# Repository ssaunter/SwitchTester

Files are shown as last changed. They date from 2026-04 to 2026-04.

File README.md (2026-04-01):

# SwitchTester
 
 SwitchTester is a 5-key switch PCB and housing to test the feel of different Cherry MX switches. Addressable LEDs have two modes: always on (colored), and fade when pressed.

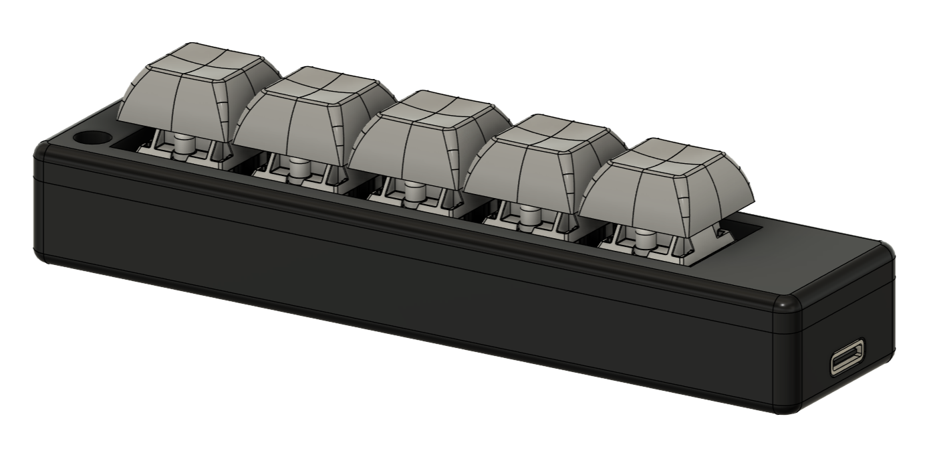
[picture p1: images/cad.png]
Full Cad


# The PCB

The PCB follows a similar architecture to the Hackpad, and upgrades with decoupling capacitors and a switch to control LED modes. The code is set up to adjust the LED modes depending on the slide switch mode.

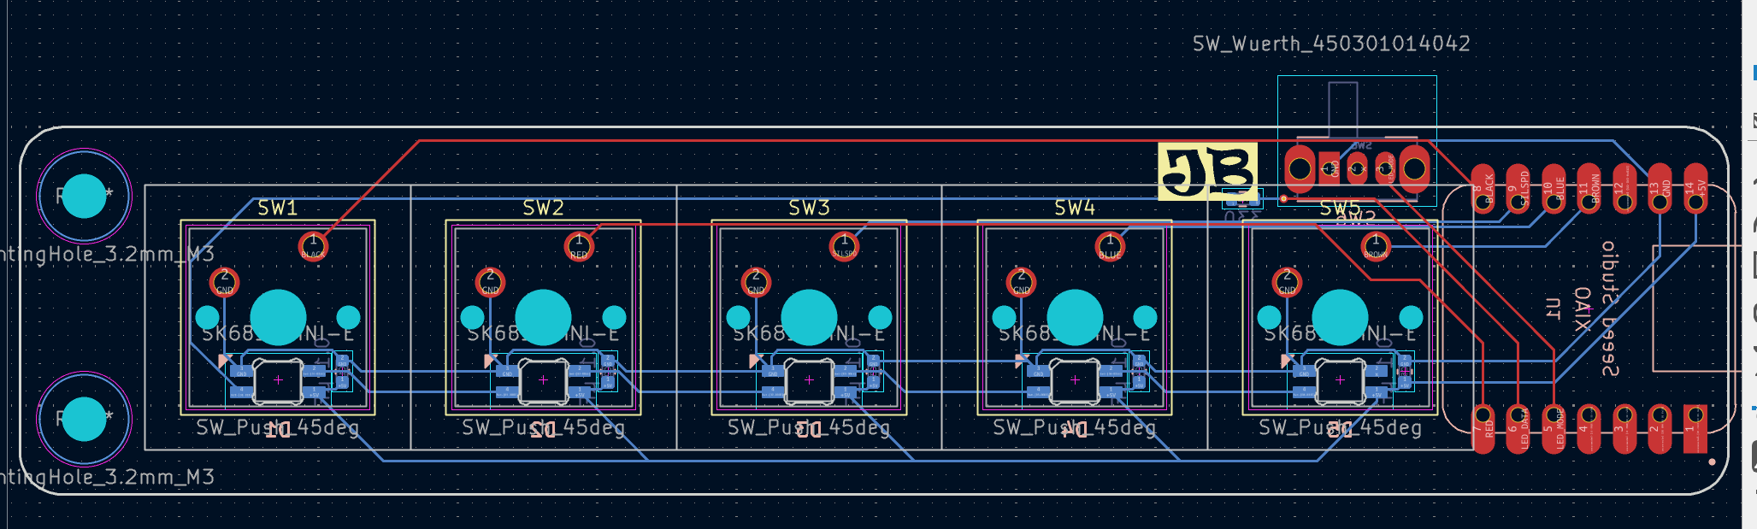
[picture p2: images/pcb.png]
PCB


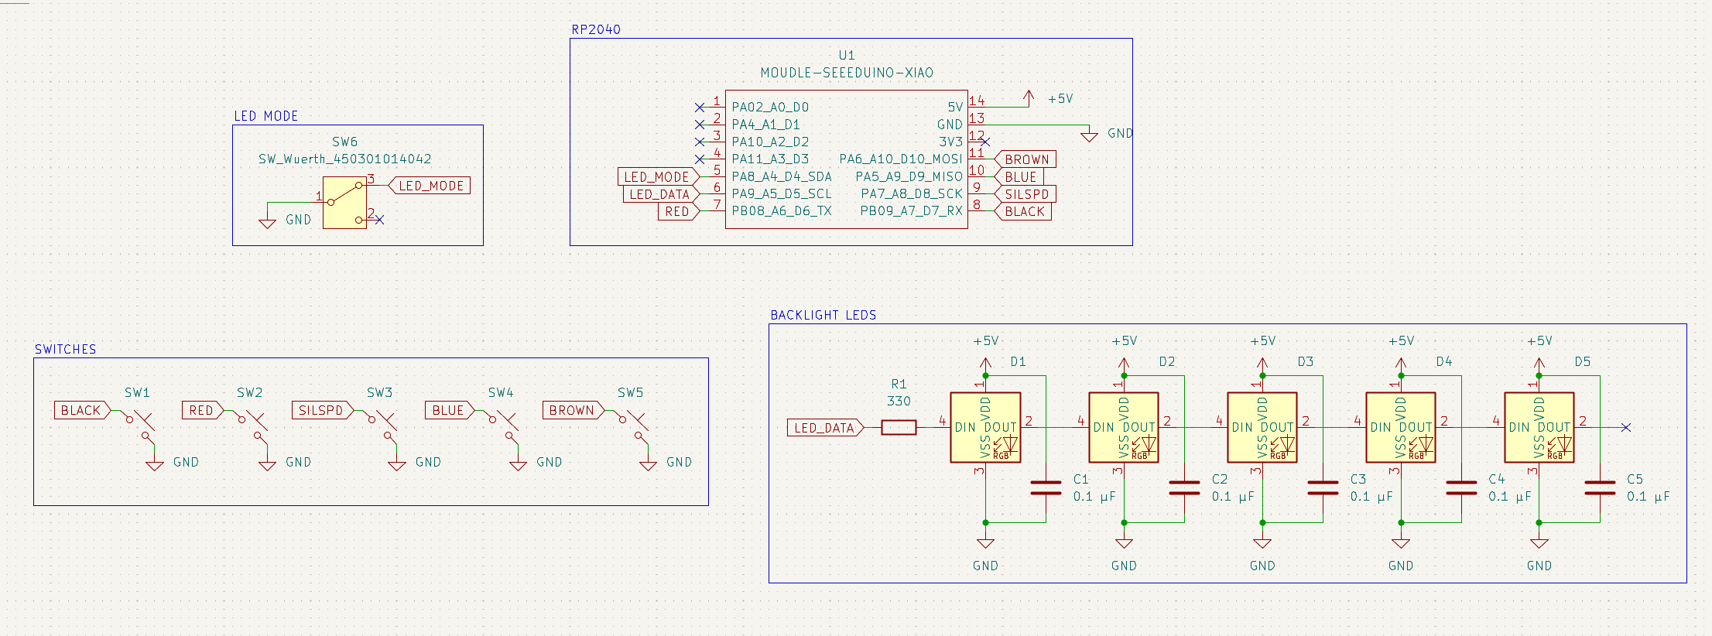
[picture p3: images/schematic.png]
Schematic


# Assembly

The lower and upper case sections are to be 3D printed. The device is assembled using 2x M3x5x5 heatset inserts and 2x M3x10 bolts. The PCB is aligned in the lower case, and the top case encloses it before being bolted down through the standoffs. It should be stable enough, but the USB-C recepticle also nicely rests into the opposite side for added stability. If I find that it is unstable even then, I can add standoffs without holes thoughout the lower case.

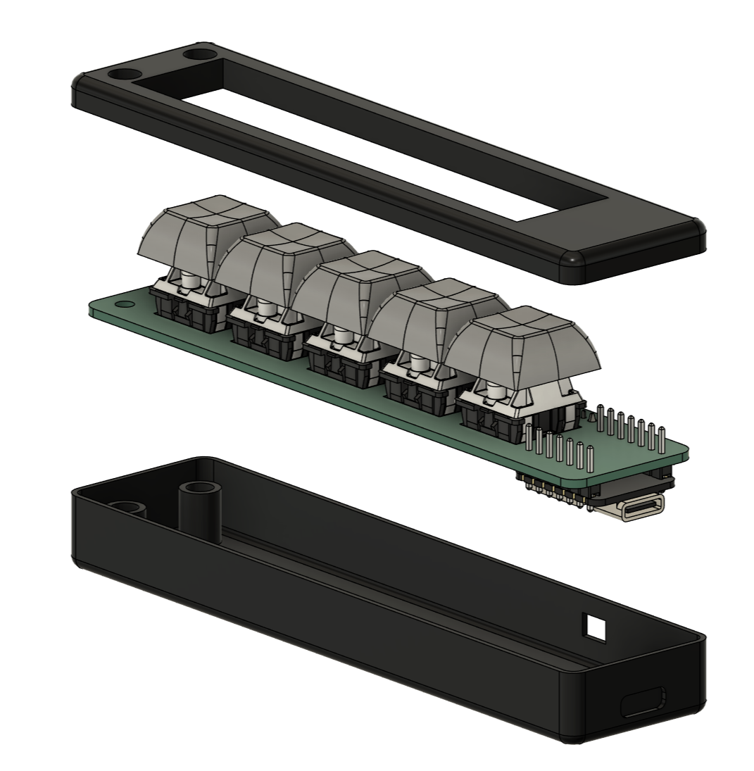
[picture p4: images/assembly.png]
Assembly


# Firmware

The code was created in the Arduino IDE, and uses the FastLED library for the SMD LEDs. The colors are based on guesses, and I will change the code after testing the values.

The first section of the code is simply setup and definitions. It sets the switches as inputs and assigns the pullup resistors, and also initializes the LED index.

The main loop determines the current LED_MODE, checks for keyswitch presses, and outputs to the LED based on the mode and user interaction. FastLED.show() is used to queue the LED instructions and send data through the LED_DATA line.

# BOM

| Part | Quantity | Price Per | Link | 
| :--- | :---: | :---: | :--- |
| **Seeduino Xiao** | 1 | $4.68 | [DigiKey](https://www.digikey.com/short/d3zzwm59) |
| **Slide Switch** | 1 | $0.65 | [DigiKey](https://www.digikey.com/short/p00mmw27) |  
| **0.1uF C 0603** | 5 | $0.08 | [DigiKey](https://www.digikey.com/short/3rn2v9pz) |
| **330ohm R 0603** | 1 | $0.10 | [DigiKey](https://www.digikey.com/short/2qztp77r) |
| **Neopixel LED 10pcs** | 1 | $2.95 | [DigiKey](https://www.digikey.com/short/n79w9mvw) |
| **Cherry MX Blue 60g** | 1 | $0.38 | [MechanicalKeyboards](https://mechanicalkeyboards.com/products/cherry-mx-blue-60g-clicky?variant=48007305003308) |
| **Cherry MX2A Red** | 1 | $0.38 | [MechanicalKeyboards](https://mechanicalkeyboards.com/products/cherry-mx2a-red-45g-linear?variant=48020634239276) |
| **Cherry MX2A Black** | 1 | $0.38 | [MechanicalKeyboards](https://mechanicalkeyboards.com/products/cherry-mx2a-black-60g-linear?variant=48014721253676) |
| **Cherry MX2A Brown** | 1 | $0.38 | [MechanicalKeyboards](https://mechanicalkeyboards.com/products/cherry-mx2a-brown-55g-tactile?variant=48020838383916) |
| **Cherry MX Blue 60g** | 1 | $0.38 | [MechanicalKeyboards](https://mechanicalkeyboards.com/products/cherry-mx-blue-60g-clicky?variant=48007305003308) |
| **DSA Keycaps** | 5 | (have) |  |
| **1x7 Male Headers** | 2 | (have) |  |
| **M3x5x5 Heatset Inserts** | 2 | (have) |  |
| **M3x10 Bolt** | 2 | (have) |  |

Totals
---
| Service  | Price | 
| :--- | :--- |
| **JLCPCB Order** |  $8.52 | 
| **DigiKey Order** |  $16.92 | 
| **MechanicalKeyboards Order** |  $12.54 | 
| **GRAND TOTAL:** |  $37.98 | 

Orders: 
---

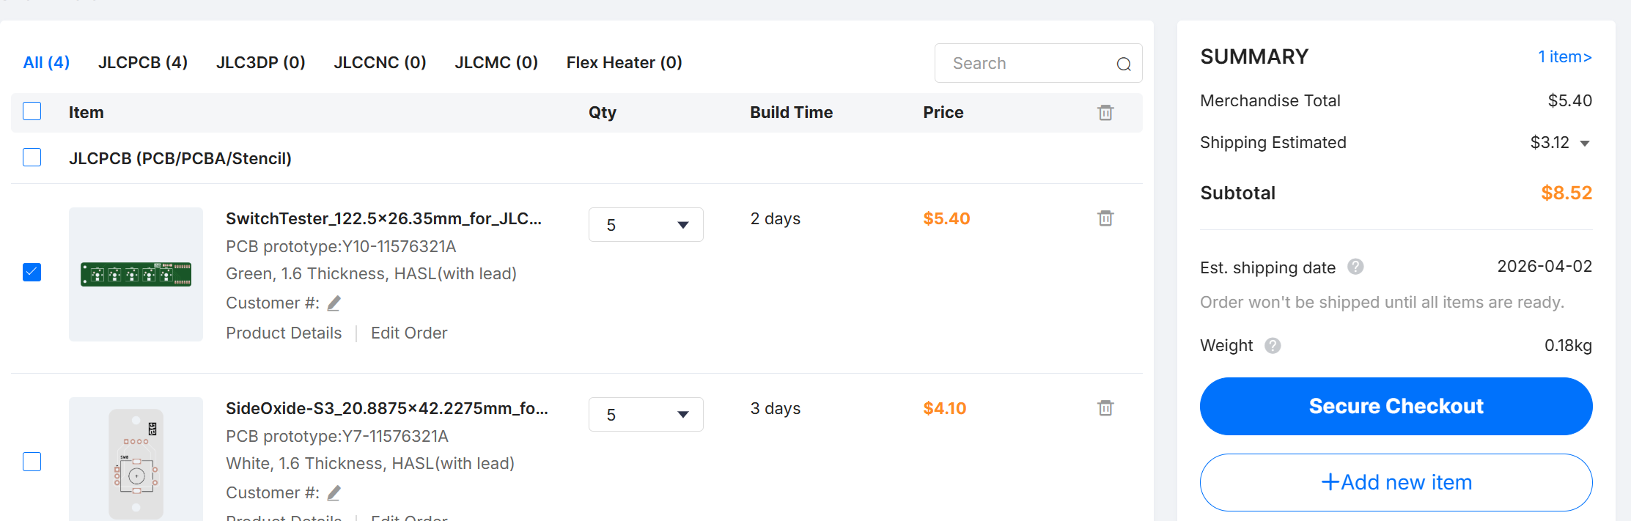
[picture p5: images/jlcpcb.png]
jlcpcb

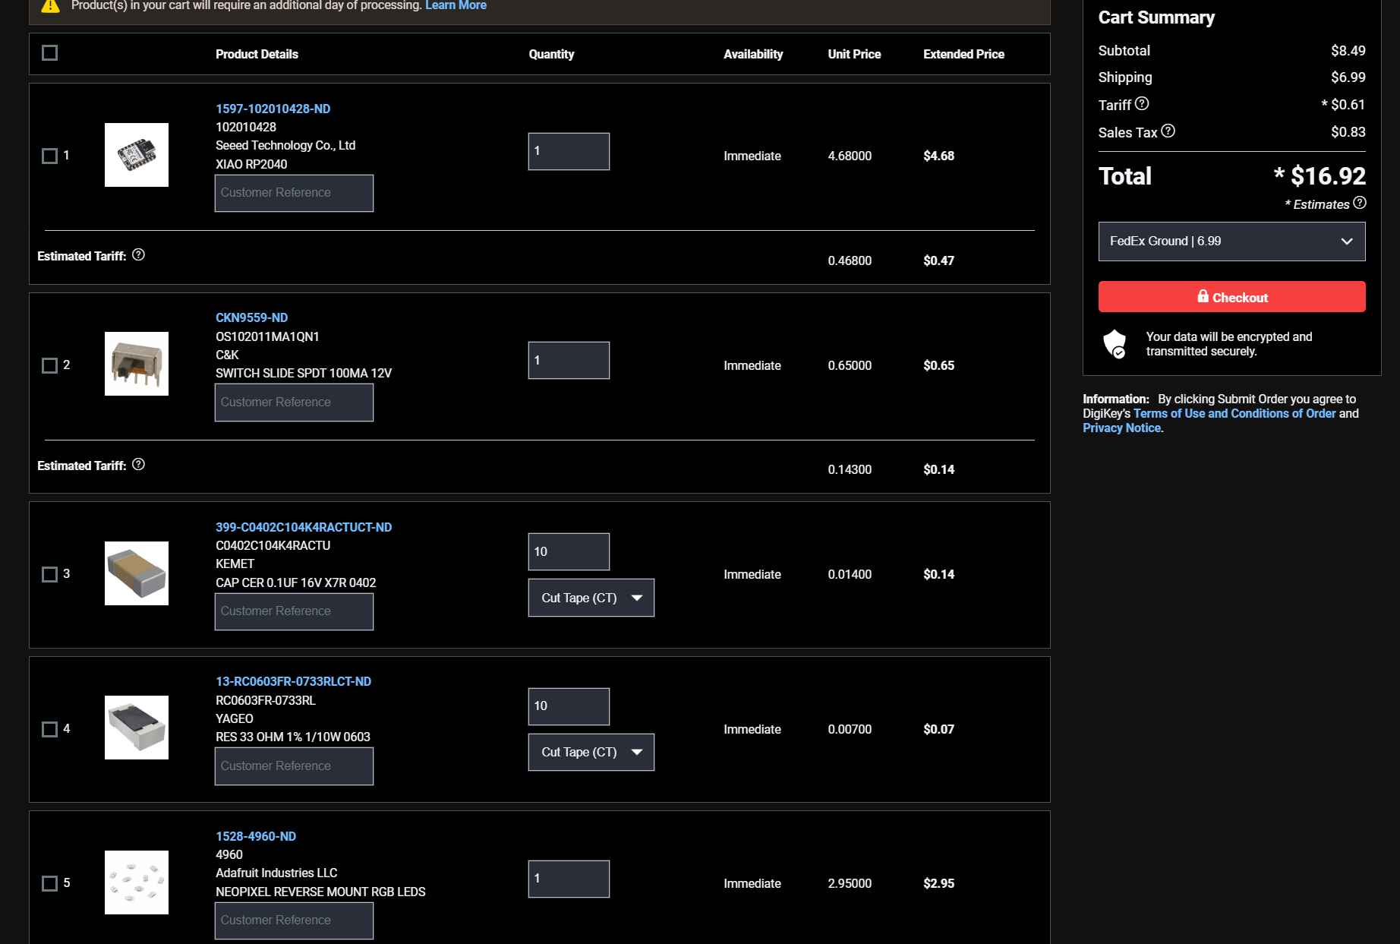
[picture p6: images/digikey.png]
digikey

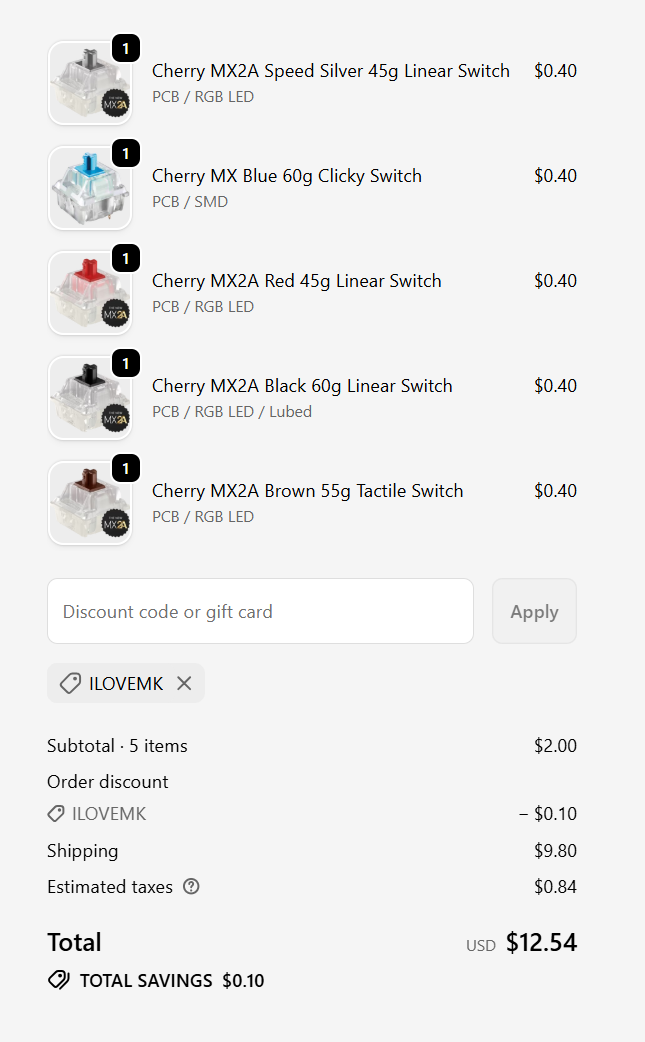
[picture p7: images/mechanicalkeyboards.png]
mechanicalkeyboards


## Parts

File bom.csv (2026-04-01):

Part | Quantity | Price Per | Link
Seeduino Xiao | 1 | 4.68 | https://www.digikey.com/short/d3zzwm59
Slide Switch | 1 | 0.65 | https://www.digikey.com/short/p00mmw27
0.1uF C 0603 | 5 | 0.08 | https://www.digikey.com/short/3rn2v9pz
330ohm R 0603 | 1 | 0.10 | https://www.digikey.com/short/2qztp77r
Neopixel LED 10pcs | 1 | 2.95 | https://www.digikey.com/short/n79w9mvw
Cherry MX Blue 60g | 1 | 0.38 | https://mechanicalkeyboards.com/products/cherry-mx-blue-60g-clicky?variant=48007305003308
Cherry MX2A Red | 1 | 0.38 | https://mechanicalkeyboards.com/products/cherry-mx2a-red-45g-linear?variant=48020634239276
Cherry MX2A Black | 1 | 0.38 | https://mechanicalkeyboards.com/products/cherry-mx2a-black-60g-linear?variant=48014721253676
Cherry MX2A Brown | 1 | 0.38 | https://mechanicalkeyboards.com/products/cherry-mx2a-brown-55g-tactile?variant=48020838383916
Cherry MX Blue 60g | 1 | 0.38 | https://mechanicalkeyboards.com/products/cherry-mx-blue-60g-clicky?variant=48007305003308
DSA Keycaps | 5 | Handled
1x7 Male Headers | 2 | Handled
M3x5x5 Heatset Inserts | 2 | Handled
M3x10 Bolt | 2 | Handled
Service | Price
JLCPCB Order | 8.52
DigiKey Order | 16.92
MechanicalKeyboards Order | 12.54
GRAND TOTAL | 37.98

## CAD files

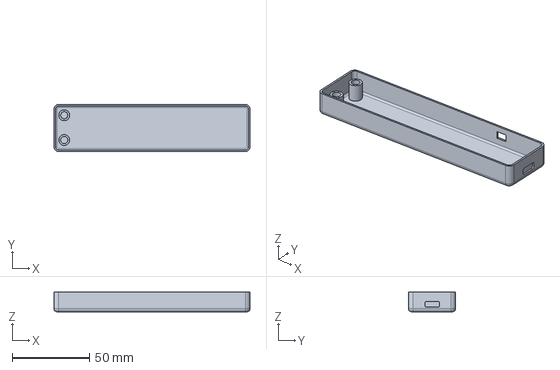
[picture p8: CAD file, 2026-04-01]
cad/Lower Case.step
126.5 x 30.4 x 12.7 mm

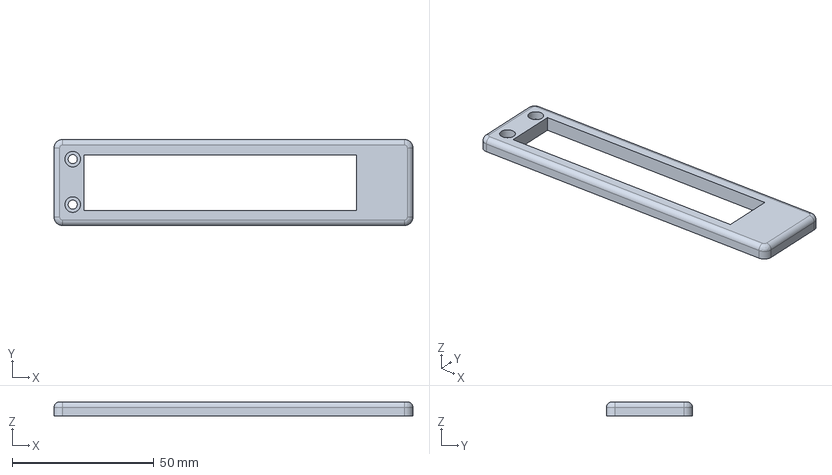
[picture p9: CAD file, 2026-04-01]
cad/Upper Case.step
126.5 x 30.4 x 5.08 mm

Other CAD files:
cad/Switch Tester.f3z

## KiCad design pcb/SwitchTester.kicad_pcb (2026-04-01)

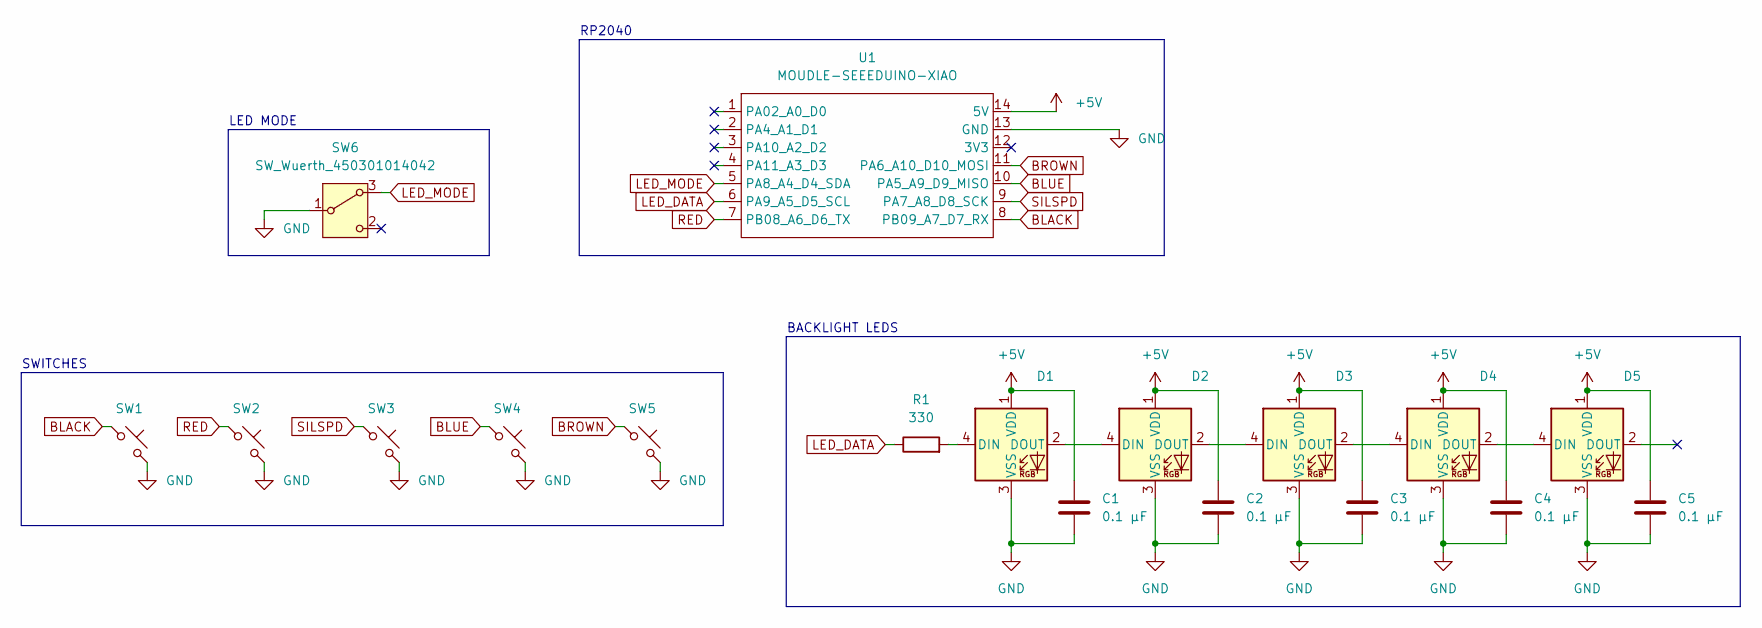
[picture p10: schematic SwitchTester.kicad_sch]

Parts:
C1, C2, C3, C4, C5: 0.1 μF; C_0603_1608Metric
D1, D2, D3, D4, D5: SK6812MINI-E; SK6812MINI-E_fixed
R1: 330; R_0603_1608Metric
SW1, SW2, SW3, SW4, SW5: SW_Push_45deg; SW_Cherry_MX_1.00u_PCB
SW6: SW_Wuerth_450301014042; SW_Slide_SPDT_Angled_CK_OS102011MA1Q
U1: MOUDLE-SEEEDUINO-XIAO; XIAO-Generic-Hybrid-14P-2.54-21X17.8MM

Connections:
+5V: C1.1, C2.1, C3.1, C4.1, C5.1, D1.1 (VDD), D2.1 (VDD), D3.1 (VDD), D4.1 (VDD), D5.1 (VDD), U1.14 (5V)
BLACK: SW1.1, U1.8 (PB09_A7_D7_RX)
BLUE: SW4.1, U1.10 (PA5_A9_D9_MISO)
BROWN: SW5.1, U1.11 (PA6_A10_D10_MOSI)
GND: C1.2, C2.2, C3.2, C4.2, C5.2, D1.3 (VSS), D2.3 (VSS), D3.3 (VSS), D4.3 (VSS), D5.3 (VSS), SW1.2, SW2.2, SW3.2, SW4.2, SW5.2, SW6.1 (B), U1.13 (GND)
LED_DATA: R1.1, U1.6 (PA9_A5_D5_SCL)
LED_MODE: SW6.3 (A), U1.5 (PA8_A4_D4_SDA)
unnamed: D1.4 (DIN), R1.2
unnamed: D1.2 (DOUT), D2.4 (DIN)
unnamed: D2.2 (DOUT), D3.4 (DIN)
unnamed: D3.2 (DOUT), D4.4 (DIN)
unnamed: D4.2 (DOUT), D5.4 (DIN)
RED: SW2.1, U1.7 (PB08_A6_D6_TX)
SILSPD: SW3.1, U1.9 (PA7_A8_D8_SCK)

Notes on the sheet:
RP2040
LED MODE
SWITCHES
BACKLIGHT LEDS

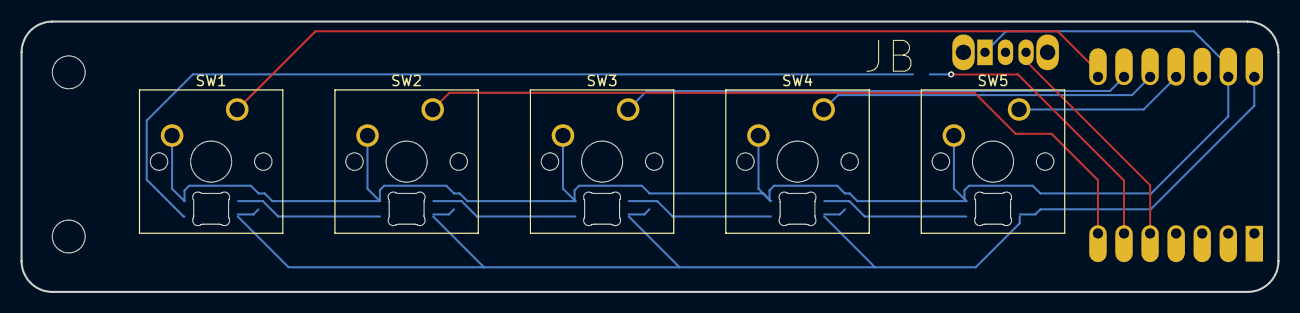
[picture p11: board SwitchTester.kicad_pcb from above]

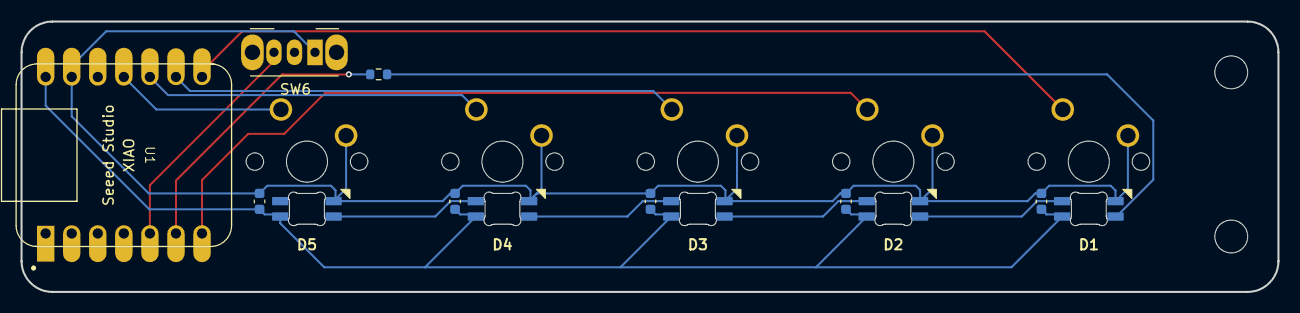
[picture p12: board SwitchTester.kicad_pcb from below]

Board: 2 copper layers, 122.5 x 26.3 mm, 18 parts (8 on the bottom side), 14 nets.

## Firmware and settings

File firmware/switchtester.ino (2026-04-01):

#include <FastLED.h>

#define NUM_LEDS      5
#define DATA_PIN      D5
#define MODE_SWITCH   D6

const int buttonPins[NUM_LEDS] = {D0, D1, D2, D3, D4}; 

CRGB leds[NUM_LEDS];

const CRGB switchColors[NUM_LEDS] = {
  CRGB(30, 30, 30),    //Black 
  CRGB::Red,           //Red
  CRGB(200, 200, 255), //Silver 
  CRGB::Blue,          //Blue
  CRGB(139, 69, 19)    //Brown 
};

//LED Reactive Mode
unsigned long lightTimers[NUM_LEDS] = {0, 0, 0, 0, 0};
const int LIGHT_DURATION = 1000; //One second fade

void setup() {
  pinMode(MODE_SWITCH, INPUT_PULLUP);

  for (int i = 0; i < NUM_LEDS; i++) {
    pinMode(buttonPins[i], INPUT_PULLUP);
  }

  FastLED.addLeds<WS2812B, DATA_PIN, GRB>(leds, NUM_LEDS);
  FastLED.setBrightness(100); //LED strength 0 - 255
}

void loop() {
  bool isAlwaysOnMode = (digitalRead(MODE_SWITCH) == LOW); //Read slider switch
  unsigned long currentTime = millis();

  for (int i = 0; i < NUM_LEDS; i++) {
    
    bool isPressed = (digitalRead(buttonPins[i]) == LOW); //Low = pressed

    if (isPressed) {
      lightTimers[i] = currentTime;
    }

    if (isAlwaysOnMode) {
      leds[i] = switchColors[i];
    } 
    else {
      if (currentTime - lightTimers[i] < LIGHT_DURATION) {
        leds[i] = switchColors[i]; 
      } else {
        leds[i] = CRGB::Black;     
      }
    }
  }

  FastLED.show();
  
    delay(10); 
}

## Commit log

2026-04-01 main commit
    [Lower Case.step, Upper Case.step]
2026-04-01 added hardware to bom
    [bom.csv]
2026-04-27 uploaded f3z file
    [Switch Tester.f3z]
